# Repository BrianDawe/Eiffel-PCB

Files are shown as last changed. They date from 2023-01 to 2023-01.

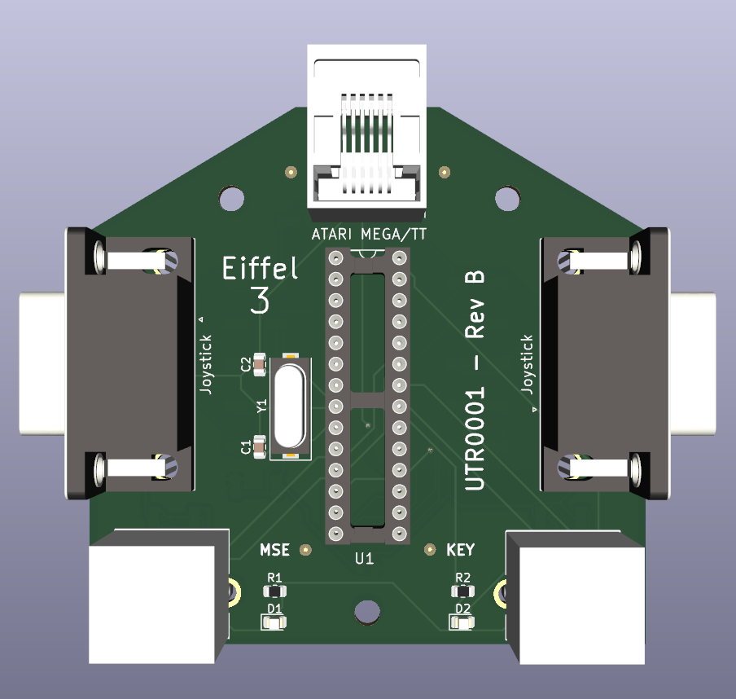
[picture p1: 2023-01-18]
UTR0001 - Eiffel - Rev B/Eiffel-0001.png

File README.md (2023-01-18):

# Eiffel-PCB

This is my implementation of the Eiffel PS2 keyboard/mouse adapter for the Mega ST/TT computers

This repo contains the KiCAD project files and all gerbers needed to make the PCB's

The original Eiffel project was created by Didier Méquignon and can be found here https://didierm.pagesperso-orange.fr/eiffel-e.htm

The firmware can be downloaded from Didier's page.

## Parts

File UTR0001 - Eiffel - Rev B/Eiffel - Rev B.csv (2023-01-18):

Component Count: | 41
Ref | Qnty | Value | Footprint
C1, C2, | 2 | 20pf | Capacitor_SMD:C_0805_2012Metric
C3, | 1 | 0.1uF | Capacitor_SMD:C_0805_2012Metric
D1, D2, | 2 | LED | LED_SMD:LED_0805_2012Metric
J1, J2, | 2 | Mini-DIN-6 | Din Sockets:MD60SM
J3, J5, | 2 | DB9_Male | Connector_Dsub:DSUB-9_Male_Horizontal_P2.77x2.84mm_EdgePinOffset7.70mm_Housed_MountingHolesOffset9.12mm
J4, | 1 | 6P6C | Connector_RJ:RJ12_Amphenol_54601
R1, R2, R4, R5, R6, R7, R8, R17, R19, R21, R23, R25, | 12 | 470R | Resistor_SMD:R_0805_2012Metric
R3, R9, R10, R11, R12, R13, R14, R15, R16, R18, R20, R22, R24, | 13 | 10K | Resistor_SMD:R_0805_2012Metric
R26, R27, R28, R29, | 4 | 10k | Resistor_SMD:R_0805_2012Metric
U1, | 1 | PIC16F876-XXISP | Package_DIP:DIP-28_W7.62mm_Socket
Y1, | 1 | 4MHz | Crystal:Crystal_SMD_HC49-SD

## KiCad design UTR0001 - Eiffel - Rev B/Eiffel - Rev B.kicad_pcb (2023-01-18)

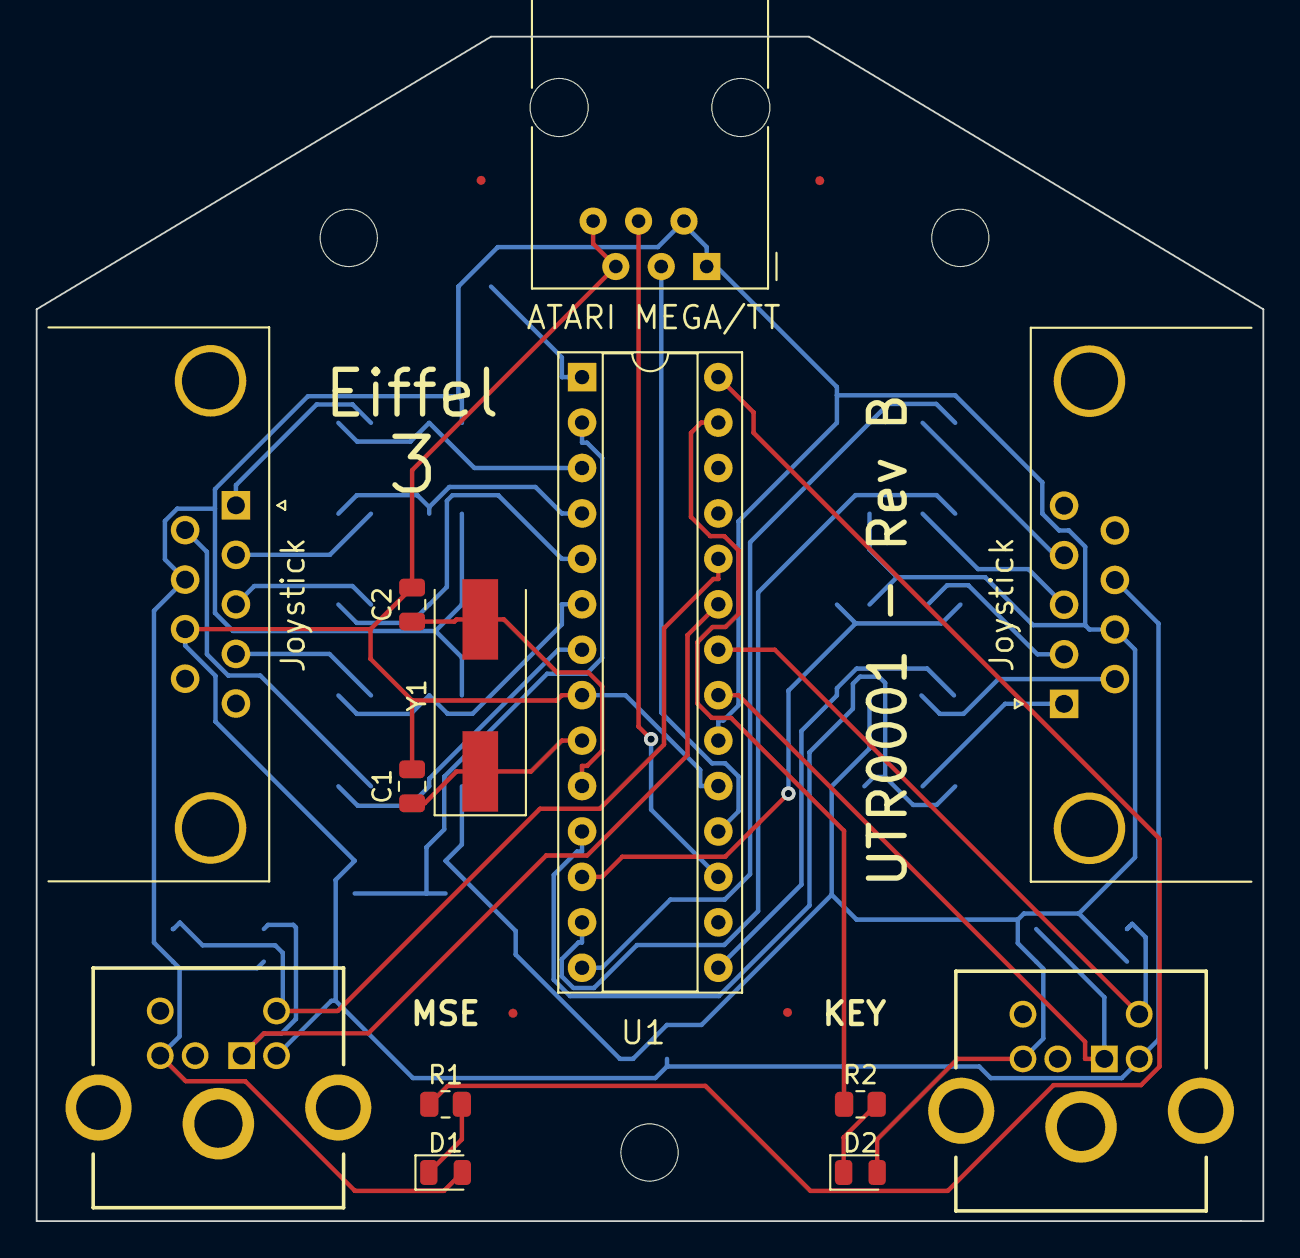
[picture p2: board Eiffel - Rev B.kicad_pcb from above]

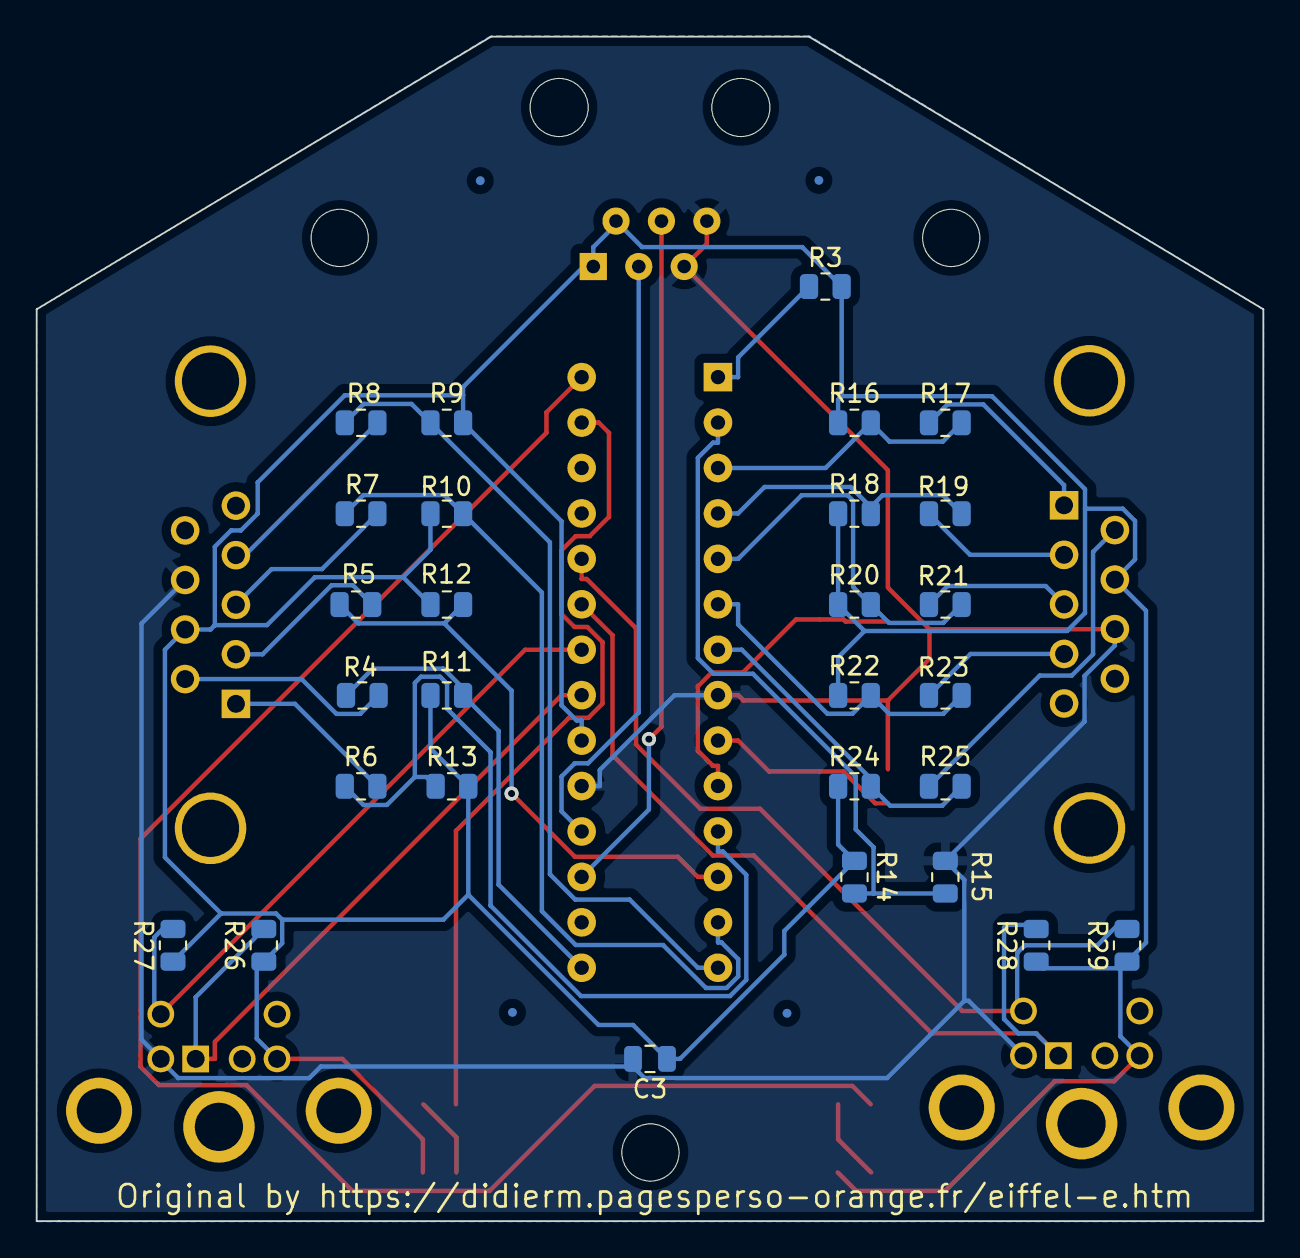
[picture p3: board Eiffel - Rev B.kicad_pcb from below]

Board: 2 copper layers, 68.6 x 66.2 mm, 41 parts (28 on the bottom side), 36 nets.

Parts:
ATARI MEGA/TT: 6P6C; RJ12_Amphenol_54601
C1, C2: 20pf; C_0805_2012Metric
C3: 0.1uF; C_0805_2012Metric
D1, D2: LED; LED_0805_2012Metric
Joystick: DB9_Male; DSUB-9_Male_Horizontal_P2.77x2.84mm_EdgePinOffset7.70mm_Hou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
Joystick#2: DB9_Male; DSUB-9_Male_Horizontal_P2.77x2.84mm_EdgePinOffset7.70mm_Hou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
KEY: Mini-DIN-6; MD60SM
MSE: Mini-DIN-6; MD60SM
R1, R2, R4, R5, R6, R7, R8, R17, R19, R21, R23, R25: 470R; R_0805_2012Metric
R3, R9, R10, R11, R12, R13, R14, R15, R16, R18, R20, R22, R24: 10K; R_0805_2012Metric
R26, R27, R28, R29: 10k; R_0805_2012Metric
U1: PIC16F876-XXISP; DIP-28_W7.62mm_Socket
Y1: 4MHz; Crystal_SMD_HC49-SD

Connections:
GND: ATARI MEGA/TT.5, ATARI MEGA/TT.6, C1.2, C2.2, C3.2, Joystick.8, Joystick#2.8, KEY.3, MSE.3, R15.2, U1.8 (VSS), U1.19 (VSS)
unnamed: C1.1, U1.9 (OSC1/CLKI), Y1.1
unnamed: C2.1, U1.10 (OSC2/CLKO), Y1.2
unnamed: ATARI MEGA/TT.1, ATARI MEGA/TT.2, C3.1, D1.2 (A), D2.2 (A), Joystick.7, Joystick#2.7, KEY.4, MSE.4, R3.1, R9.2, R10.2, R11.2, R12.2, R13.2, R14.1, R16.1, R18.1, R20.1, R22.1, R24.1, R26.1, R27.1, R28.1, R29.1, U1.20 (VDD)
unnamed: D1.1 (K), R1.2
unnamed: D2.1 (K), R2.2
unnamed: KEY.1, R26.2, U1.21 (INT/RB0)
unnamed: KEY.5, R27.2, U1.22 (RB1)
unnamed: MSE.1, R28.2, U1.23 (RB2)
unnamed: MSE.5, R29.2, U1.24 (PGM/RB3)
unnamed: Joystick#2.1, R6.2
unnamed: Joystick#2.2, R5.1
unnamed: Joystick#2.3, R7.1
unnamed: Joystick#2.4, R8.1
unnamed: Joystick#2.6, R4.1
unnamed: ATARI MEGA/TT.3, U1.18 (RC7/DT/RX)
unnamed: ATARI MEGA/TT.4, U1.17 (RC6/CK/TX)
unnamed: Joystick.1, R17.2
unnamed: Joystick.2, R19.2
unnamed: Joystick.3, R21.2
unnamed: Joystick.4, R23.2
unnamed: Joystick.6, R25.2
unnamed: R1.1, U1.28 (PGD/RB7)
unnamed: R2.1, U1.27 (PGC/RB6)
unnamed: R3.2, U1.1 (~MCLR/Vpp)
unnamed: R8.2, R9.1, U1.14 (RC3/SCK/SCL)
unnamed: R7.2, R10.1, U1.13 (RC2/CCP1)
unnamed: R4.2, R11.1, U1.15 (RC4/SDI/SDA)
unnamed: R5.2, R12.1, U1.12 (RC1/T1OSI/CCP2)
unnamed: R6.1, R13.1, U1.11 (RC0/T1OSO/T1CKI)
unnamed: R14.2, R15.1, U1.2 (AN0/RA0)
unnamed: R16.2, R17.1, U1.3 (AN1/RA1)
unnamed: R18.2, R19.1, U1.4 (Vref-/AN2/RA2)
unnamed: R20.2, R21.1, U1.5 (Vref+/AN3/RA3)
unnamed: R22.2, R23.1, U1.6 (T0CKI/RA4)
unnamed: R24.2, R25.1, U1.7 (~SS/AN4/RA5)
